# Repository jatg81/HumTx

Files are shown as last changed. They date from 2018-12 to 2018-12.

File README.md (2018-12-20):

# HumTx
Mod Deshumedecedor de closet DHM150 IMACO

Se modifica el deshumedecedor para que vacie automaticamente el agua del recipiente interno y lo envie hacia un deposito externo, ademas se incorporo un sensor de humedad y temperatura del aire. Los datos del estado del humedecedor son enviados inalambricamente a un Raspberry Pi (EmonPi).
<p align="center">
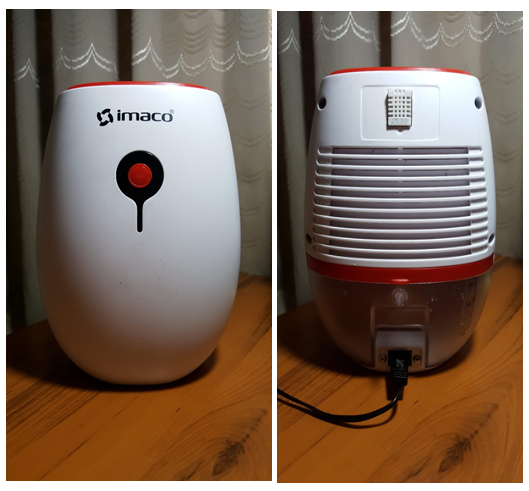
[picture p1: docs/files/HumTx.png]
  
</p>

Caracteristicas de fabrica
- Modelo: DHM150
- Dimensiones: 21x17x13 cm
- Potencia: 25W
- Recipiente: 500mL
- Capacidad de remoción de humedad 200-300 ml/día

Principales componentes internos:
- *Microcontrolador: Moteino USB R6
- *Sensor de nivel: HC-SR04
- *Sensor humedad-temperatura: DHT22
- Enfriador celda peltier: TEC01-12703
- Ventilador: TX8025L12S
- *Bomba: Mini sumergible bomba de agua DC 2.5-6V -- 120L/H

<p align="center">
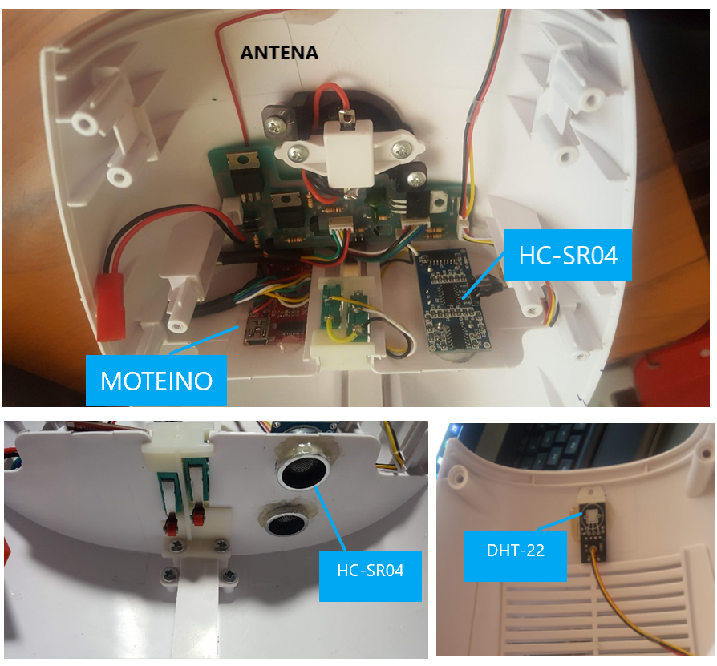
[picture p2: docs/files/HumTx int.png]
  
</p>

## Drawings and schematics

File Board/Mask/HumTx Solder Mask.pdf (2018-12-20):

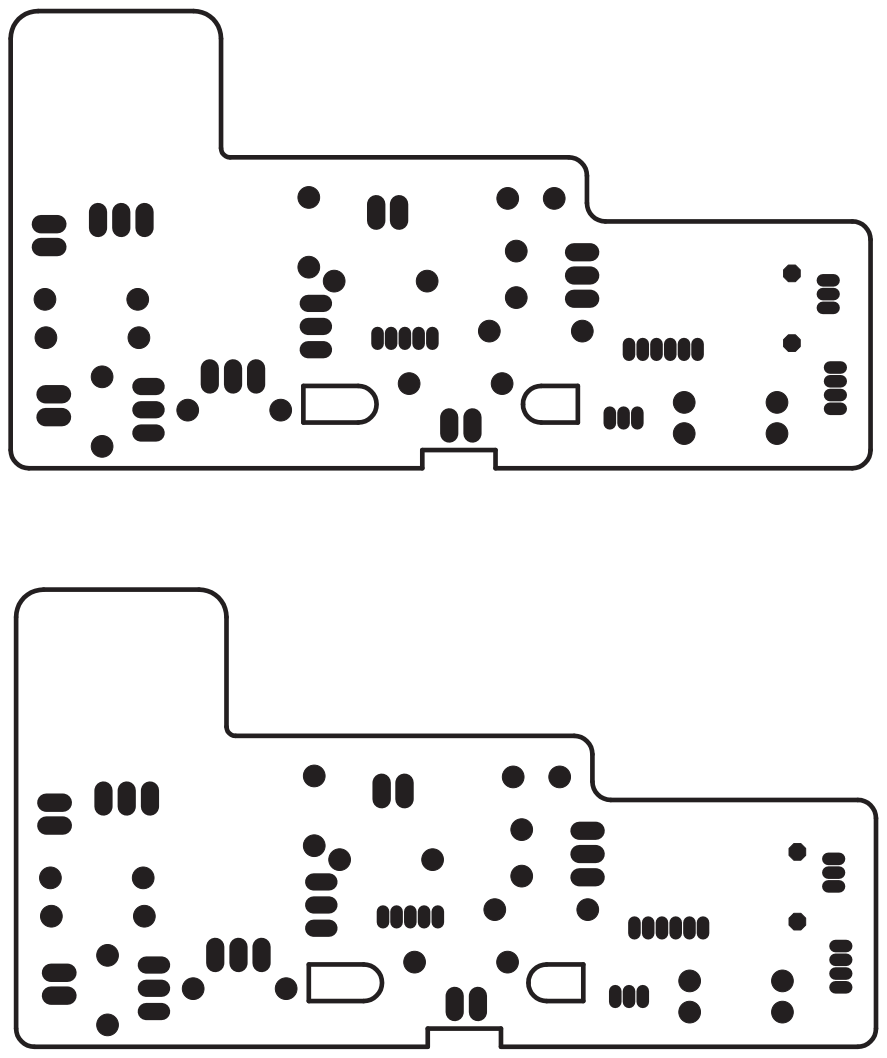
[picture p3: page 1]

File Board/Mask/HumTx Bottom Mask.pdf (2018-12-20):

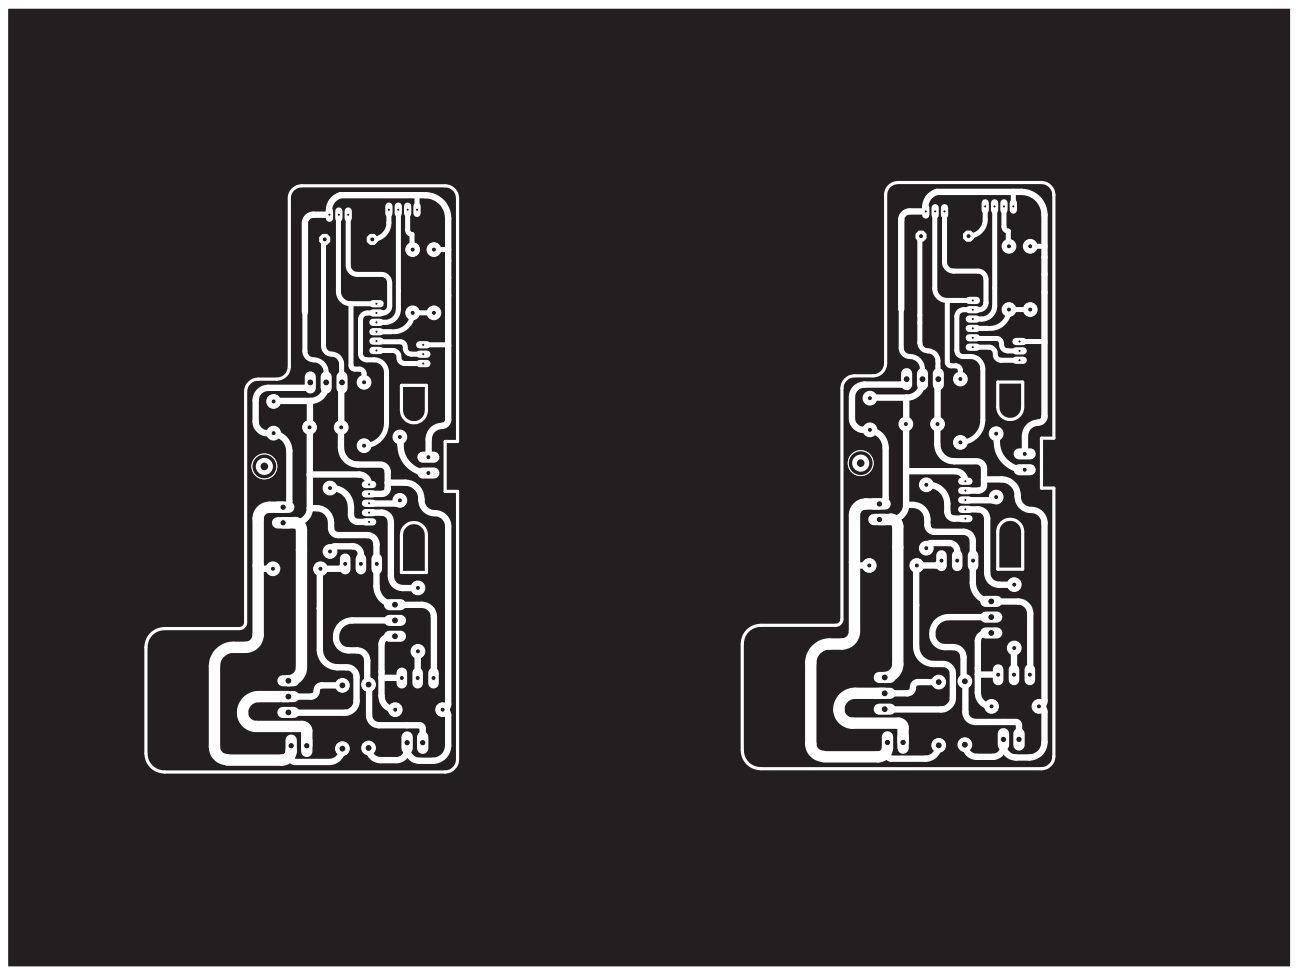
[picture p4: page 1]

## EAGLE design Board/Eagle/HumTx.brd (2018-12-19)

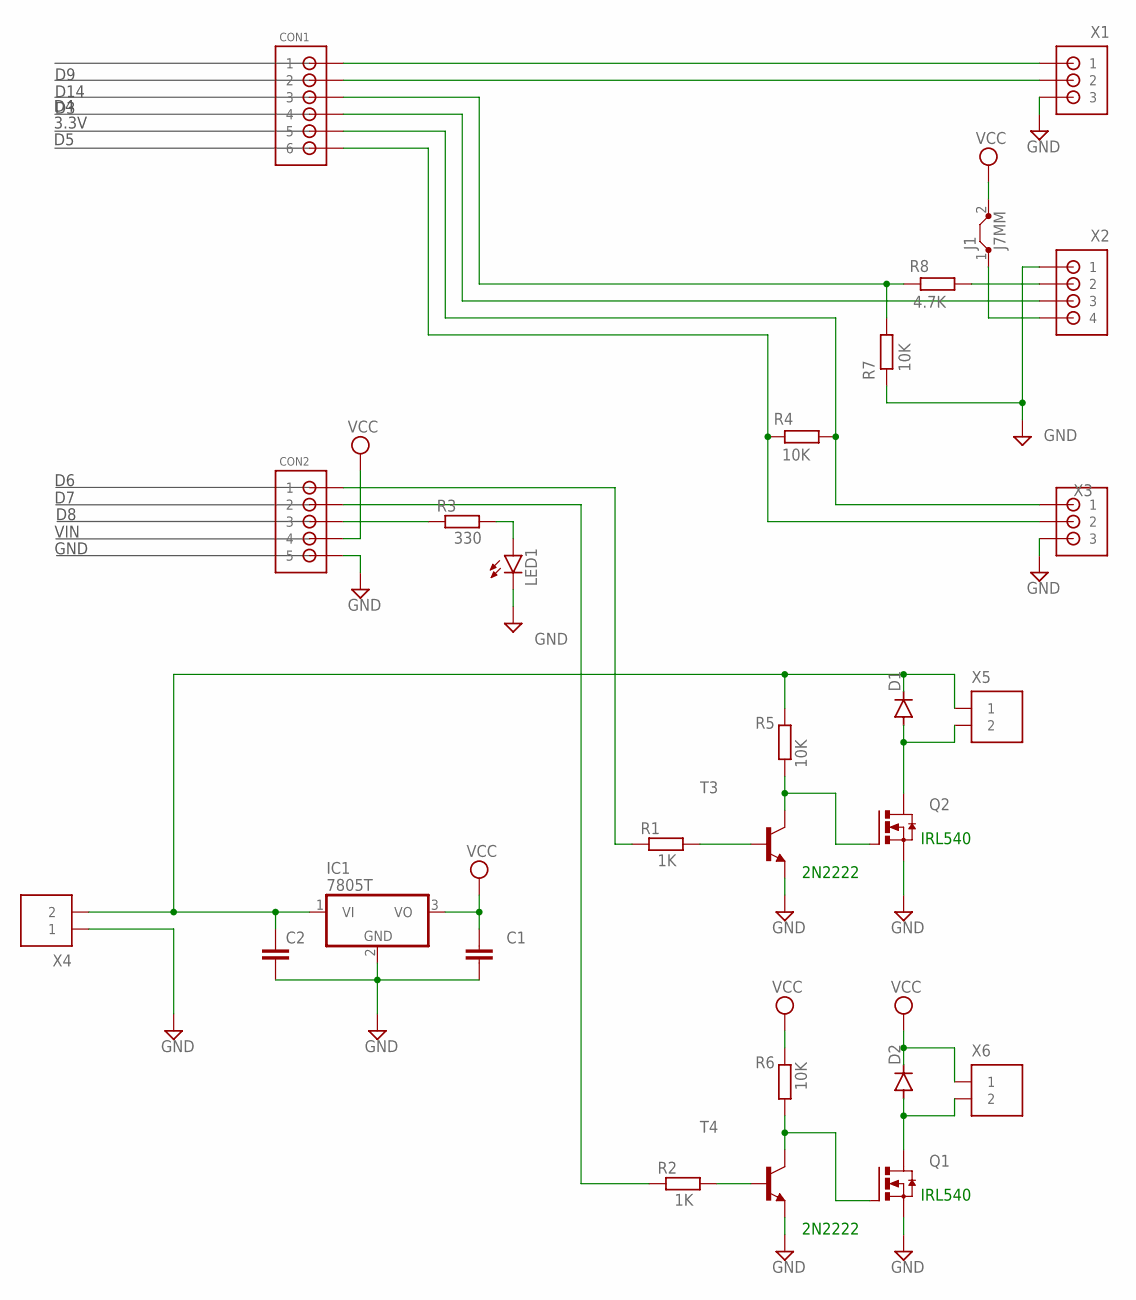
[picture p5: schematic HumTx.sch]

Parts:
C1, C2: C5/7.2; C5B7.2
CON1: B6B-ZR
CON2: B5B-ZR
D1, D2: 1N4004; DO41-10
IC1: 7805T; TO220H
J1: J7MM; 07
LED1: LED5MM
Q1, Q2: IRF3704-H; TO220BH
R1, R2: 1K; 0207/10
R3: 330; 0207/10
R4, R7: 10K; 0207/10
R5, R6: 10K; 0204/7
R8: 4.7K; 0207/10
T3, T4: -NPN-TO92-EBC; TO92-EBC
X1, X3: B3B-ZR
X2: B4B-ZR
X4, X5, X6: MKS1852-6-0-202

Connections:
GND: C1.2, C2.2, CON2.5, IC1.2 (GND), LED1.K (C), Q1.S, Q2.S, R7.2, T3.E, T4.E, X1.3, X2.1, X3.3, X4.1
unnamed: R2.2, T4.B
unnamed: R1.2, T3.B
unnamed: Q2.G, R5.1, T3.C
unnamed: LED1.A, R3.2
unnamed: D1.A, Q2.D, X5.2
unnamed: D2.A, Q1.D, X6.2
unnamed: CON1.5, R4.1, X3.1
unnamed: CON1.1, X1.1
unnamed: CON1.2, X1.2
unnamed: CON1.6, R4.2, X3.2
unnamed: CON1.4, X2.3
unnamed: CON1.3, R7.1, R8.2
unnamed: CON2.3, R3.1
unnamed: CON2.1, R1.1
unnamed: CON2.2, R2.1
unnamed: C2.1, D1.C, IC1.1 (VI), R5.2, X4.2, X5.1
unnamed: Q1.G, R6.1, T4.C
unnamed: R8.1, X2.2
unnamed: J1.1, X2.4
VCC: C1.1, CON2.4, D2.C, IC1.3 (VO), J1.2, R6.2, X6.1

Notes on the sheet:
IRL540
2N2222
D14
3.3V
VIN
GND

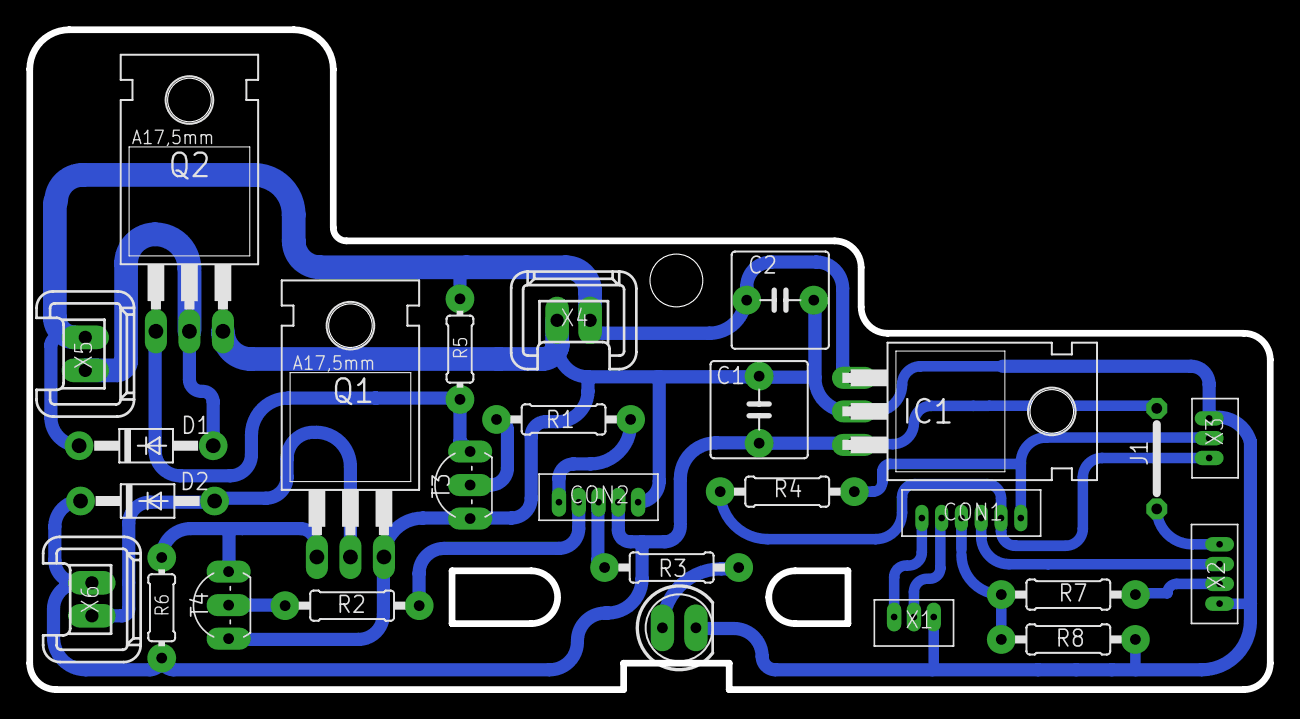
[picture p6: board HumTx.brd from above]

Board: 2 copper layers, 94.0 x 50.0 mm, 27 parts (0 on the bottom side), 21 nets.

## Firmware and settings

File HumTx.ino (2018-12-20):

/****************************************************************************/
/*  Status             ErrCode                                              */
/*   0:ON             10: Not Tank                                          */
/*   1:OFF            20: Low Level                                         */
/*   2:ERROR          30: Hi Level                                          */                                                              */
/****************************************************************************/
#include <hcsr04.h>
#include <DHT.h>
#include <RF69Mod.h>

#define TRIG_PIN      3
#define ECHO_PIN      4
#define DHTPin        5  
#define COOLER        6
#define PUMP          7
#define LED           8
#define SW_NOT_TANK   9 
#define SW_HI_LEVEL   14

#define RF_freq       RF69_433MHZ                                                               //Frecuencia de transmision 433Mhz
#define LO_LEVEL_MM   70                                                                        //Distancia en mm bajo nivel
#define HI_LEVEL_MM   40                                                                        //Distancia en mm alto nivel (minima distancia que puede leer el sensor 33mm)
#define alfa          0.2                                                                       //Factor filtro EMA

HCSR04 sensorLevel;
DHT dht;

unsigned long currentTime,cloopTime1,cloopTime2;
int levelperc,status,errCode;
const int nodeIdEmonPi=5;                                                                            // Id del EmonPi
const int nodeId = 13;                                                                               // emonTx RFM12B nodo ID
const int netGroup = 210;                                                                            // emonTx RFM12B  grupo ID
float levelmm,humAmb,tempAmb;
typedef struct { int dat0,dat1,dat2,dat3,dat4;} PayloadTX;       
PayloadTX humtx; 

void getTankLevel (){ //Función que obtiene el nivel del tanque en porcentaje
  levelmm=alfa*float(sensorLevel.readAvgDisctanceInMm(50))+(levelmm*(1-alfa)); //Se filtra el promedio de 50 lecturas del sensor de nivel
  if(levelmm > LO_LEVEL_MM){
      levelperc=0;
      if(levelmm > LO_LEVEL_MM + 40){
        status=2;
        errCode=20;
      }
  }
  else {
    if (levelmm < HI_LEVEL_MM){
      levelperc=100;
      if(levelmm < HI_LEVEL_MM - 5){
        status=2;
        errCode=30;
      }
    }
    else levelperc=(0,0.0633*pow(levelmm,2)-10.096*levelmm+402.22); // Se lineariza la señal del nivel del tanque
  }
}

void sendData (){
   humtx.dat0=tempAmb*10;
   humtx.dat1=humAmb*10;
   humtx.dat2=levelperc;
   humtx.dat3=status;
   humtx.dat4=errCode;
   rf69_sendNow (nodeId, &humtx, sizeof humtx);                //Envio de datos          
}

void printdata (){
  Serial.print("Distance: ");
  Serial.print(levelmm);
  Serial.print("mm");
  Serial.print(" -- ");
  Serial.print(levelperc);
  Serial.print("%");
  Serial.print(" Temp: ");
  Serial.print(tempAmb);
  Serial.print(" Hum: ");
  Serial.print(humAmb);
  Serial.print(" status: ");
  Serial.print(status);
  Serial.print(" errcode: ");
  Serial.print(errCode);
  Serial.print(" TK: ");
  Serial.print(!digitalRead(SW_NOT_TANK));
  Serial.print(" SW-HI: ");
  Serial.println(!digitalRead(SW_HI_LEVEL));
}

void setup() {    

  pinMode(SW_NOT_TANK, INPUT);
  digitalWrite(SW_NOT_TANK, HIGH);
  pinMode(SW_HI_LEVEL, INPUT);
  digitalWrite(SW_HI_LEVEL, HIGH);
  pinMode(COOLER, OUTPUT);
  digitalWrite(COOLER, HIGH);
  pinMode(PUMP, OUTPUT);
  digitalWrite(PUMP, HIGH);
  pinMode(LED, OUTPUT);
  digitalWrite(LED, HIGH);
  sensorLevel.init(TRIG_PIN, ECHO_PIN);
  sensorLevel.setDelayBetweenAvgMeasurementsInMs(9);
  levelmm=sensorLevel.readAccurateDisctanceInMm();
  
  //Serial.begin(9600); // Starts the serial communication

  for(int j=0;j<20;j++){
    digitalWrite(LED, !digitalRead(LED));
    delay(250);
  }
  dht.setup(DHTPin);
  rf69_initialize(nodeId, RF_freq, netGroup);
  cloopTime1,cloopTime2 = millis();
}

void loop(){

  currentTime = millis();

  if (!digitalRead(SW_NOT_TANK) && digitalRead(SW_HI_LEVEL)){   // Encendido del enfriador 
    digitalWrite(COOLER, LOW);
    status=1;
    errCode=0;
  } else{
    digitalWrite(COOLER, HIGH);                                 //Apagado del enfriador
    status=2;
    if (digitalRead(SW_NOT_TANK))   errCode=10;
    if (!digitalRead(SW_HI_LEVEL))  errCode=30;
  }

  getTankLevel ();

  if(levelmm<40  && !digitalRead(SW_NOT_TANK)){                 //Encendido bomba cuando el tanque esta lleno
    digitalWrite(PUMP, LOW);
  }
  if(levelmm>85){                                               //Apagado bomba cuando el tanque esta vacio
    delay (2000);
    digitalWrite(PUMP, HIGH);
  }

  if(currentTime-cloopTime1 >= 1000) {
    cloopTime1 = currentTime;
    sendData();                                                 //Transmisión de datos por RF cada 1 segundo
    //printdata();
  }
  
  if(currentTime-cloopTime2 >= 5000) {                          //Lectura del sensor de temperatura y humedad cada 5 segundos
    cloopTime2 = currentTime;
    for (int k=0;k<3;k++){
      tempAmb=dht.getTemperature();
      if(!isnan(tempAmb)) break;
      tempAmb=-127;
      delay(500);
    }
    for (int k=0;k<3;k++){
      humAmb=dht.getHumidity();
      if(!isnan(humAmb)) break;
      humAmb=-127;
      delay(500);
    }
  }
}
